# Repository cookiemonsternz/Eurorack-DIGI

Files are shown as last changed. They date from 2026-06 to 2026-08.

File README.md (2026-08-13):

# DIGI
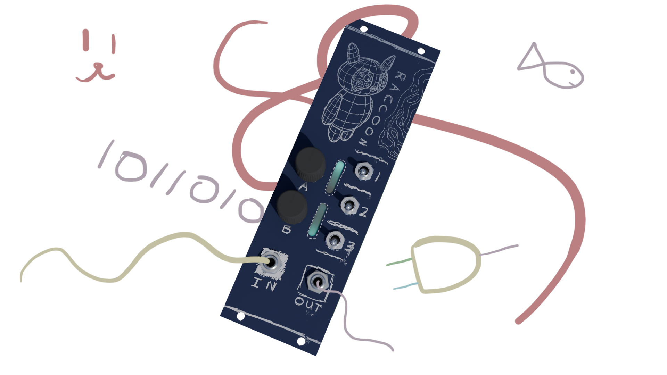
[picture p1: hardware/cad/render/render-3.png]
Render 3

_FPGA based programmable eurorack effects module_

#### What?
Yet another in my line of eurorack modules. This module is a prototyping platform for fpga based effects. It has a basic mono audio codec, two rotary encoders and 3 switches. It has two small led based displays in order to provide some feedback for the encoders. It consists of two user programmable leds with a diffuser.

DIGI utilises an ice40UP5K fpga chip, featuring 5280 luts and a 48Mhz clock. This is accompanied by a USB-SPI interface for easy programming. The board includes 64Mbits of PSRAM via single channel SPI and 256kbits of flash EEPROM. 

#### Why?
First and foremost: FPGAs are cool. Unfortunately, the world is quite starved of easy to use FPGA devboards, and especially so one which is designed for audio. This module acts as an easy to use prototyping environment for audio processing which would not be possible on MCUs.

This does kind of act as a counterpart to REV, but with an FPGA as to an MCU. This provides a bit more flexibility (and performance) and also provides a lot more memory to play with. 

#### How to use?
The board has a simple audio input and output, as well as two rotary encoders and switches, which are user programmable.

In terms of getting it set up, you'll need to program the fpga. To do this, follow the general setup guides for lattice radiant. It should be configured as a project for the iCE40UP5K-SG48I. An example showing the board acting as a basic buffer is available in the gateware folder.

Once assembled, the board uses a standard eurorack connector as well as standard 3.5mm audio jacks for input and output. Pretty plug and play :)

## Renders
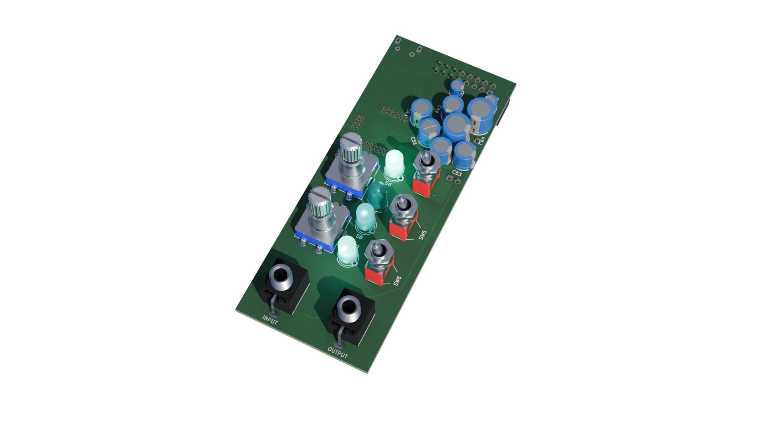
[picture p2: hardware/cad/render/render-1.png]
Render 1

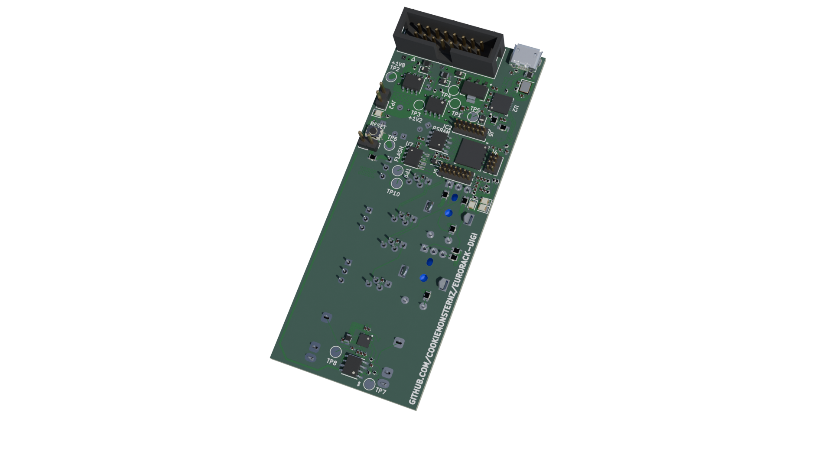
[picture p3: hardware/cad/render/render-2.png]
Render 2

Board front
Board back
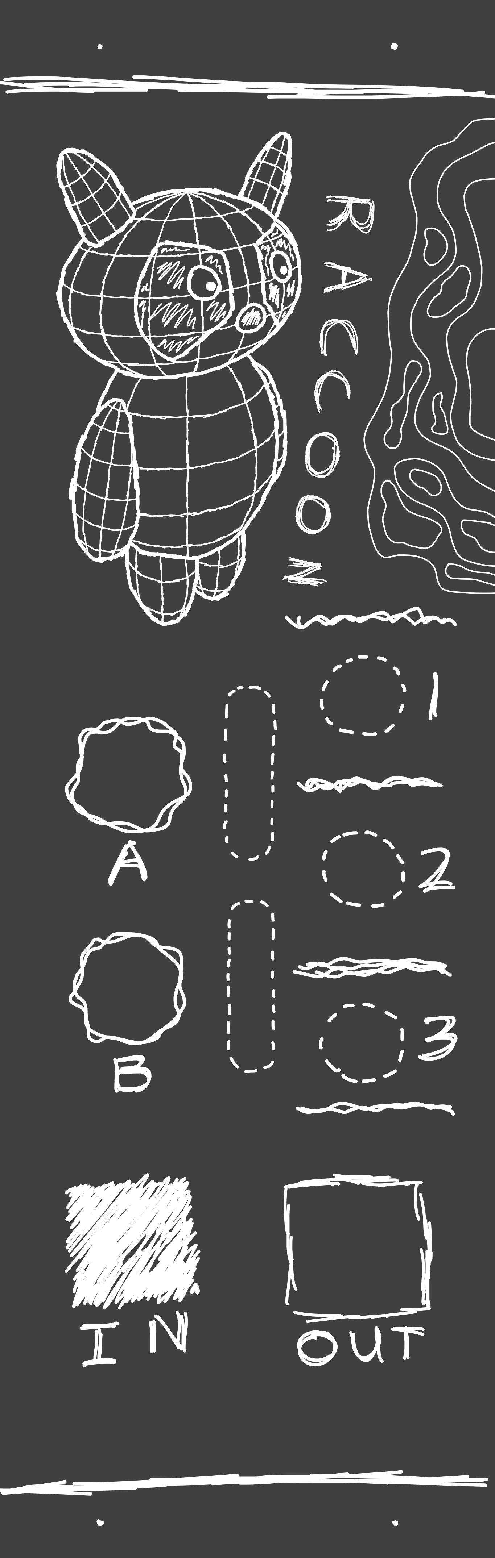
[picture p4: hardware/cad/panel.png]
Panel art


## Schematics
Schematics are available as a [pdf](./hardware/digi/plots/digi.pdf) or as svgs in [hardware/digi/plots](./hardware/digi/plots/).

## Zine Page
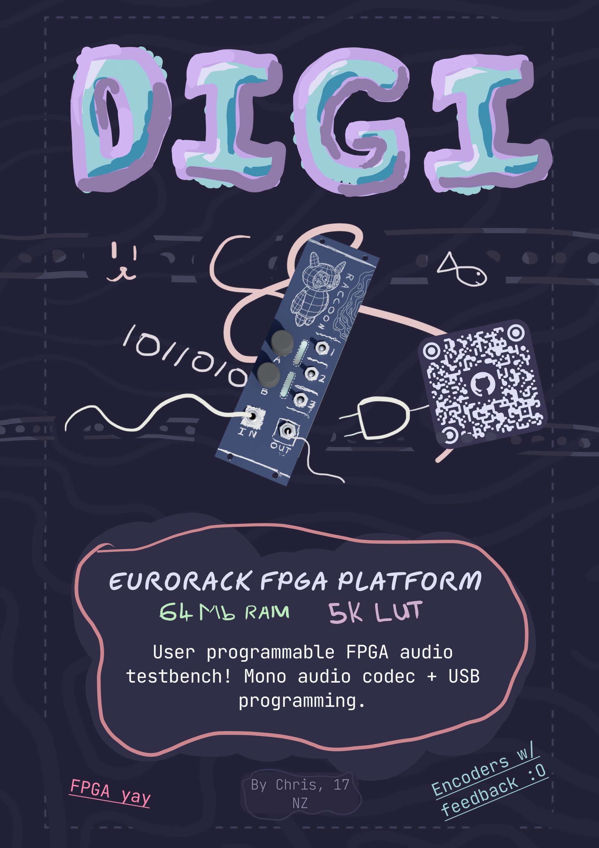
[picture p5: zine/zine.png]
Zine page


## BOM
_Needed is how many I personally need :)_
| Part | Quantity | Needed | Source | Link | Lot / Min Amount | Unit | Net | Running |
|---|---|---|---|---|---|---|---|---|
| **Capacitors** | | | | | | | | |
| 20p Cap, 0402 | 2 | 2 | JLCPCB | https://jlcpcb.com/partdetail/1906-0402CG200J500NT/C1554 | 1 | $0.0021 | $0.0042 | $0.01 |
| 10n Cap, 0402 | 4 | 4 | JLCPCB | https://jlcpcb.com/partdetail/15869-CL05B103KB5NNNC/C15195 | 1 | $0.0025 | $0.0100 | $0.01 |
| 100n Cap, 0402 | 25 | 25 | JLCPCB | https://jlcpcb.com/partdetail/291005-CL05B104KB54PNC/C307331 | 1 | $0.0076 | $0.1900 | $0.20 |
| 1u Cap, 0402 | 12 | 12 | JLCPCB | https://jlcpcb.com/partdetail/53938-CL05A105KA5NQNC/C52923 | 1 | $0.0069 | $0.0828 | $0.28 |
| 4.7u Cap, 0402 | 6 | 6 | JLCPCB | https://jlcpcb.com/partdetail/24469-CL05A475MP5NRNC/C23733 | 1 | $0.0107 | $0.0642 | $0.35 |
| 10u Cap, 0402 | 2 | 2 | JLCPCB | https://jlcpcb.com/partdetail/16204-CL05A106MQ5NUNC/C15525 | 1 | $0.0186 | $0.0372 | $0.38 |
| 22u Cap, 0603 | 1 | 1 | JLCPCB | https://jlcpcb.com/partdetail/60514-CL10A226MQ8NRNC/C59461 | 1 | $0.0224 | $0.0224 | $0.41 |
| 10u Electrolytic Cap, P1.5xD4.0 | 2 | 0 | LCSC | https://www.lcsc.com/product-detail/C503219.html | 10 | $0.0143 | $0.0000 | $0.41 |
| 47u Electrolytic Cap, P2.5xD6.3 | 5 | 0 | LCSC | https://www.lcsc.com/product-detail/C107641.html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 | 10 | $0.0665 | $0.0000 | $0.41 |
| 470u Electrolytic Cap, P5xD10.0 | 2 | 0 | LCSC | https://www.lcsc.com/product-detail/C338196.html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 | 5 | $0.1883 | $0.0000 | $0.41 |
| **Resistors** | | | | | | | | |
| 0? Resistor, 0402 | 6 | 6 | JLCPCB | https://jlcpcb.com/partdetail/17853-0402WGF0000TCE/C17168 | 1 | $0.001  | $0.0066 | $0.41 |
| 10? Resistor, 0402 | 1 | 1 | JLCPCB | https://jlcpcb.com/partdetail/25820-0402WGF100JTCE/C25077 | 1 | $0.001  | $0.0009 | $0.41 |
| 100? Resistor, 0402 | 4 | 4 | JLCPCB | https://jlcpcb.com/partdetail/25819-0402WGF1000TCE/C25076 | 1 | $0.0012 | $0.0048 | $0.42 |
| 470? Resistor, 0402 | 1 | 1 | JLCPCB | https://jlcpcb.com/partdetail/25860-0402WGF4700TCE/C25117 | 1 | $0.0010 | $0.0010 | $0.42 |
| 1k? Resistor, 0402 | 2 | 2 | JLCPCB | https://jlcpcb.com/partdetail/12256-0402WGF1001TCE/C11702 | 1 | $0.0011 | $0.0022 | $0.42 |
| 2.2k? Resistor, 0402 | 2 | 2 | JLCPCB | https://jlcpcb.com/partdetail/26622-0402WGF2201TCE/C25879 | 1 | $0.0010 | $0.0020 | $0.42 |
| 10k? Resistor, 0805 | 8 | 8 | JLCPCB | https://jlcpcb.com/partdetail/18102-0805W8F1002T5E/C17414 | 1 | $0.0034 | $0.0272 | $0.45 |
| 12k? Resistor, 0402 | 1 | 1 | JLCPCB | https://jlcpcb.com/partdetail/26495-0402WGF1202TCE/C25752 | 1 | $0.0010 | $0.0010 | $0.45 |
| 39k? Resistor, 0402 | 1 | 1 | JLCPCB | https://jlcpcb.com/partdetail/26526-0402WGF3902TCE/C25783 | 1 | $0.0011 | $0.0011 | $0.45 |
| 100k? Resistor, 0402 | 1 | 1 | JLCPCB | https://jlcpcb.com/partdetail/26484-0402WGF1003TCE/C25741 | 1 | $0.0010 | $0.0010 | $0.45 |
| 1M? Resistor, 0402 | 1 | 1 | JLCPCB | https://jlcpcb.com/partdetail/26826-0402WGF1004TCE/C26083 | 1 | $0.0011 | $0.0011 | $0.46 |
| **Diodes** | | | | | | | | |
| 1N4148WS, SOD-323 | 1 | 1 | JLCPCB | https://jlcpcb.com/partdetail/2485-1N4148WS/C2128 | 1 | $0.0092 | $0.0092 | $0.46 |
| 1N5819WS, SOD-323 | 4 | 4 | JLCPCB | https://jlcpcb.com/partdetail/GuangdongHottech-1N5819WS/C191023 | 1 | $0.0111 | $0.0444 | $0.51 |
| **Other Components** | | | | | | | | |
| TL072CDT | 1 | 1 | JLCPCB | https://jlcpcb.com/partdetail/STMicroelectronics-TL072CDT/C6961 | 1 | $0.1570 | $0.1570 | $0.67 |
| EC11 Rotary Encoder SW | 2 | 0 | Aliexpress | https://www.aliexpress.com/item/1005010400760178.html | 5 | $0.8580 | $0.0000 | $0.67 |
| SPDT Switch | 3 | 3 | Aliexpress | https://www.aliexpress.com/item/1005005370002265.html | 5 | $0.8520 | $4.2600 | $4.93 |
| PJ301M-12 Audio Jack | 2 | 0 | Aliexpress | https://www.aliexpress.com/item/1005004864182675.html | 10 | $0.4440 | $0.0000 | $4.93 |
| 2x08 IDC Connector | 1 | 0 | LCSC | https://www.lcsc.com/product-detail/C7430313.html | 5 | $0.0993 | $0.0000 | $4.93 |
| X322512MSB4SI 12MHz Crystal | 1 | 1 | JLCPCB | https://jlcpcb.com/partdetail/YXC_CrystalOscillators-X322512MSB4SI/C9002 | 1 | $0.0740 | $0.0740 | $5.00 |
| USB B Micro Port | 1 | 1 | JLCPCB | https://jlcpcb.com/partdetail/SHOUHAN-MicroXNJ/C404969 | 1 | $0.0406 | $0.0406 | $5.04 |
| 256kB EEPROM, AT24C256C-SSHL-T  | 1 | 1 | JLCPCB | https://jlcpcb.com/partdetail/MicrochipTech-AT24C256C_SSHLT/C6482 | 1 | $0.3886 | $0.3886 | $5.43 |
| 64Mbit PSRAM, APS6404L-SQN-SN | 1 | 1 | JLCPCB | https://jlcpcb.com/partdetail/APMemory-APS6404L_SQNSN/C5360304 | 1 | $2.4684 | $2.4684 | $7.90 |
| Neopixel tht, 5mm | 8 | 8 | Aliexpress | https://www.aliexpress.com/item/1005006447915276.html | 20 | $0.2595 | $5.1900 | $13.09  |
| Audio Codec, ES8311 | 1 | 1 | JLCPCB | https://jlcpcb.com/partdetail/1044199-ES8311/C962342 | 1 | $0.5514 | $0.5514 | $13.64  |
| Reset Button | 1 | 1 | JLCPCB | https://jlcpcb.com/partdetail/XUNPU-TS_1088AR02016/C720477 | 1 | $0.0551 | $0.0551 | $13.69  |
| Ferrite Bead, 600R | 2 | 2 | JLCPCB | https://jlcpcb.com/partdetail/Sunlord-GZ2012D601TF/C1017 | 1 | $0.0323 | $0.0646 | $13.76  |
| 22uH Inductor, 0805 | 2 | 2 | JLCPCB | https://jlcpcb.com/partdetail/Sunlord-SDFL2012T220KTF/C32375 | 1 | $0.0689 | $0.1378 | $13.90  |
| LED Yellow | 1 | 1 | JLCPCB | https://jlcpcb.com/partdetail/Hubei_KENTOElec-KT0805Y/C2296 | 1 | $0.0152 | $0.0152 | $13.91  |
| LED Green | 1 | 1 | JLCPCB | https://jlcpcb.com/partdetail/Hubei_KENTOElec-KT0805G/C2297 | 1 | $0.0162 | $0.0162 | $13.93  |
| LED Red | 1 | 1 | JLCPCB | https://jlcpcb.com/partdetail/85425-NCD0805R1/C84256 | 1 | $0.0133 | $0.0133 | $13.94  |
| AMS1117-3.3 | 1 | 1 | JLCPCB | https://jlcpcb.com/partdetail/Advanced_MonolithicSystems-AMS1117_33/C6186 | 1 | $0.1971 | $0.1971 | $14.14  |
| XL1509-ADJ | 2 | 2 | JLCPCB | https://jlcpcb.com/partdetail/XLSEMI-XL1509ADJE1/C74192 | 1 | $0.2717 | $0.5434 | $14.68  |
| **Other** | | | | | | | | |
| PCB | 1 | 1 | JLCPCB | NA | 5 | $1.6600 | $8.3000 | $22.98  |
| Aluminium Plate (100x200x2mm) | 1 | 1 | Aliexpress | https://www.aliexpress.com/item/1005007160296738.html | 1 | $6.2300 | $6.2300 | $29.21  |
| **Total** | | | | | | | | $29.21  |

| **Totals** | **Money**  |
|---|---|
| Aliexpress, Inc. Shipping + Tax | $24.57 |
| JLCPCB, Inc. Shipping + Tax | $38.84 |
| Total | $63.41 |

## CAD Links
Heres the links to the CAD source, Onshape:
[Panel source](https://cad.onshape.com/documents/423b155ae421053f9c0db9a4/w/13826012c5a1515169c92444/e/776c4f51f2d171959c208a60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)

## Directory Structure
- **hardware/**
    - **bom/** - BOM Files (CSV and LibreOffice Calc)
    - **cad/** - CAD Files
        - **render/** - Files for rendering (inc. gltf models)
    - **digi/** - KiCad files
        - **lib/** - External libraries
        - **production/** - Production files (Gerber, etc.)
        - **plots/** - Schematic plot
- **journals/**
- **zine/** - Zine page

#### This project was created for [Hack Club](https://hackclub.com/) - [Fallout](https://fallout.hackclub.com/)

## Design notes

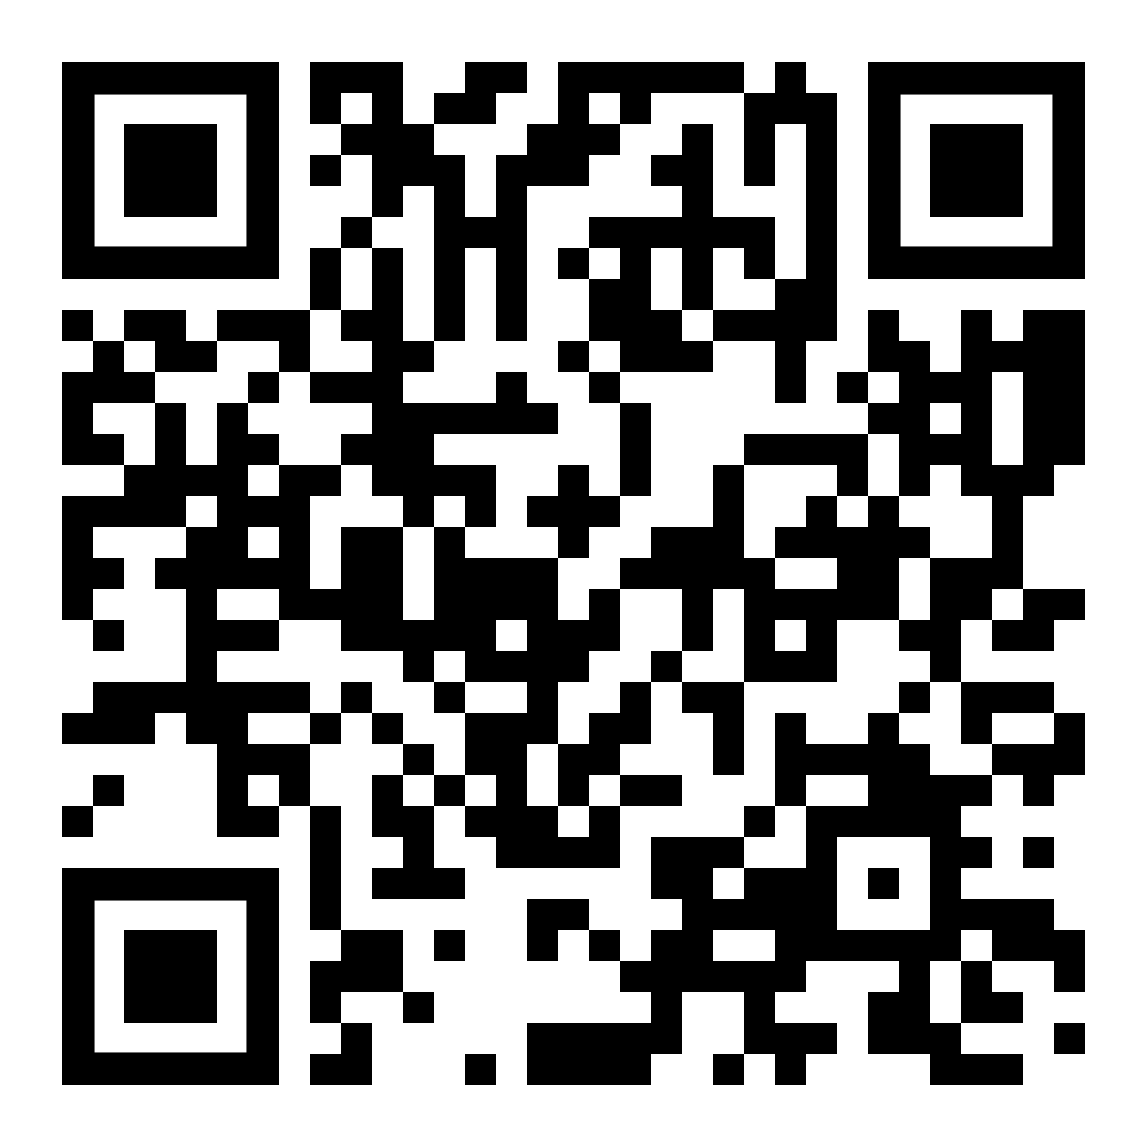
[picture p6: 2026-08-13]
hardware/digi/github-qr.png

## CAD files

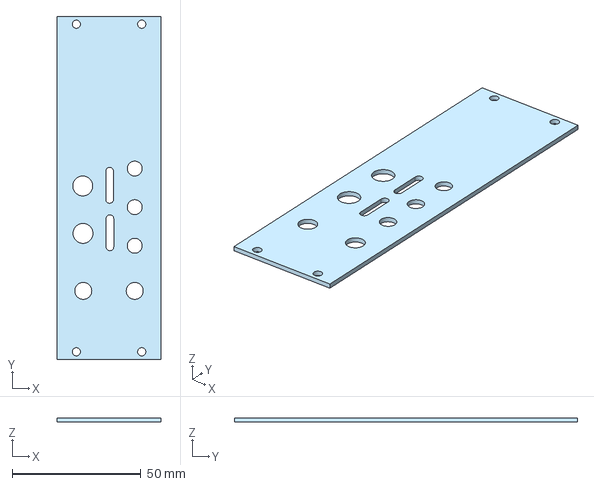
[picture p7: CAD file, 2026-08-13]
hardware/cad/panel.step
40.2 x 133.3 x 1.59 mm

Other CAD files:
hardware/cad/panel.dxf

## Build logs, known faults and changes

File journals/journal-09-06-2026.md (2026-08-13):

# DIGI Journal 2 - 09/06/2026

Hello again!
Today I've already done some work tidying up loose ends with the audio codec and usb-spi interface, and I'm happy to say that they are both much closer to complete. It takes ages to do anything really with them, sooo much datasheet reading lol.

Anyways, I'm about to move on to the power section for the board, and have quickly mocked it up in figma:
Power layout

And going into kicad:
Kicad power section
Just went with LDOs / buck-buck conv. which were basic parts. 1.2V is the very lower end for the chip but it should be fine

---

A couple days later and I've just been doing a bunch of random odd bits around the place. 
I've added a couple inputs (2 rotary encoders and 3 switches), as well as 8 neopixels for encoder feedback (4 per encoder).
Encoder feedback leds

I also got the crystal sorted out, just using basic parts etc.
Overall, I reckon the schematic is very very close to being done :) I'm going to do a final pass over everything, and maybe add another feature or two, as I've still got 13 unused GPIO pins.

In terms of audio as I mentioned earlier, I'm going to go with the approach of discarding half the differential pair. It'll still work and be mostly fine, and it saves me from making a balanced to unbalanced converter, which turns out to be suprisingly complex.

---

I've decided to add a little flash chip as well, just for persistent configuration. Just using a cheap wee one from the basic parts. Uses i2c so I can just redo the i2c bus I've already got set up.
Flash

I've also just figured that I might need a level shifter for the sdram :( It runs at 1.8V and the fpga runs at 3.3V.

Yep my suspicions were correct, it can only tolerate ~2.4V. There is an easier solution however: Because each bank of the ice40 chip has a seperate vcc, I can just power the spi block at 1.8V.

A problem with this is that the USB interface ic runs at 3.3v, so I've decided to just use two spi sets. The ice40 has two hardware spi interfaces, so I've put one of them on bank 1 at 1.8V for the sdram, and the other on bank 2 at 3.3V for the USB-SPI interface. Pretty chill :)

And after doing a final pass and adding a bunch of test points, I'm happy to call the schematic complete! 

---

Next up, footprint assignment / BOM, god I'm not looking forward to this lol.

---

Welp it took about as long as I thought it would, but its done now :)
BOM
Annnd of course half my time didn't get tracked because the resume button broke :( Oh well, time to get onto the pcb.

And heres how its looking:
PCB Pre-layout

I'm going to aim for a pretty dense layout, as there won't be much on the top of the board and I don't want it to look tooo sparse. I might go for an 8hp module this time, which would mean 40.64mm wide panel and thus probs a ~40x100mm board.

And yeah, this is looking pretty doable:
PCB Pre-layout w/ Board outline

This is what I'm thinking for the general layout:
General layout

---

Ended the day here, continued in next journal :)

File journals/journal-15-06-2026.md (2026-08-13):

# DIGI Journal 3 - 15/06/2026

Welp its been a minute! Getting straight back into the swing of things though. Goal for today is a finished pcb and panel, maybe even some panel art and if I'm really lucky, a readme :)

First things first though, I'd like to make this board just a tiny bit more general purpose by exposing some headers :) Just some of the pins on each bank.
Headers
Pretty simple stuff, not too much of note to talk about, just hope it isn't too annoying to route lol.

---

I've layed out the first two ldo's, the 3.3V and 1.8V, looks like this:
LDO 1 and 2 layout

And all three:
Die ganze dinge

The audio codec:
Audio codec layout

Going through the ftdi chip now and I've decided to swap out the electrolytic caps with mlcc ones, just to save some space. Heres the layed out section:
FTDI Layout

I've also decided to cut the number of neopixels in half, they're just really big lol.
They'll be layed out like so:
Neopixel layout
I'll have a little slot with some diffusion paper and a barrier between the two encoders and that should give a decent vertical slider like representation.

The routing here is super basic:
Neopixels layout pcb

Now the hard part: I've started routing the actual fpga chip, and have made it to about here:
FPGA Routing pt 1
Theres still a few more components to go in (just the reset and done led), which shouldn't be terrible, but man these headers are complicating things :sob: I'm going to leave it for a minute and route another section, but it does need to get done eventually.

Welp, I sorted out the flash which was quite easy, as well as all the pullups for the encoders but now theres nothing left to do but route stuff around the fpga :O

ARrrgghh 

Tomorrow job :)

Heres where I ended off for today:
PCB at end of day

Gn :)

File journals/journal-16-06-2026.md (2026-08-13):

# DIGI Journal 4 - 16/06/2026

Hello again! Its tomorrow now :)
I've already done a bunch of work before starting this journal, but generally, its just been a bunch of routing. Heres the result of that so far:
Routing
Everything is routed except for the power! Yippee!

For the power, I do need to take a bit of care. I've got a dedicated layer just to do a bunch of big pours which should be pretty chill.

---

And a wee bit later heres the fully routed layout!
Fully routed

And after a bit more work, no more drc errors :)
DRC Errors

Well there are a few, but none of them are actual errors. Theres also a crapton of silkscreen warnings because I haven't gone through and sorted it out yet.

Heres the front silkscreen:
Front silkscreen

And the back:
Back silkscreen

I do want to add a bit of art to both sides, but that can wait for later. I was going to use a QR code for the thing but I didn't have space and there were far too many holes, text is just easier :)

And that (mostly) concludes the board design section of this project! Yayyy! Next up is the panel and such, but that will have to wait for tomorrow unfortunately.

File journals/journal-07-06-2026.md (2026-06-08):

# DIGI Journal 1 - 07/06/2026

Hello again! The 4 am brain demands another project, and in the depths of my deranged, sleep deprived mind I have come up with an absolutely horrifying idea for the next model in my line of effects. 

A digital effect pedal based on an fpga chip.

I've been looking for an excuse to screw around with fpga for ages, and dsp is one application they're really well suited for. My aim is for this to be a general purpopse-ish design, so I can program a bunch of different effects in the future. 

I've already done a bit of research on parts, and decided what I'm going to use, so I'll just give a quick overview here:

### The FPGA Chip

I've elected to go with the ice40UP5k. There were a couple main factors that went into this decision:
- Its available on jlcpcb pcba
- Its cheap-ish ($8.00, most are more)
- Has a good amount of luts (5k :))
- Is very popular (and thus well supported)

It generally looks like a pretty simple and usable chip, which is very appealling to me.

### Ram

Because I want this to be reasonably general purpose, I'm going to need more than the MBit sram included in the ice40up5k. At a sample rate of 44.1khz and bit depth of 12, that would give me only ~1.5 seconds of audio storage, and I would like a wee bit more for longer reverbs / delays. I've decided to go with the 
APS6404L-SQN-SN chip, which is a 64MBit PSRAM (pretty much sram but a different technology, only used it because it was cheap and for the features I'm about to mention). 
I chose this chip because:
- Storage capacity is good (like 2 mins of audio)
- Cheap (cheaper than sram, thats for sure, still about 3 bucks but thats fine)
- QSPI interface - A lot of sram uses parallel interfaces, but those would eat up way too many pins on the fpga (one i was looking at earlier used 37, the fpga has 48 :O)

### Audio Codec

Unfortunately I can't pull the same trick I did with the rp2040 for audio, and just pwm out, adc in, as the ice40up doesn't have an adc. To that end, I'll need an audio codec, which provides an audio input and output via i2c. I've just gone with the most stocked option on jlcpcb, which was the  . Its a mono audio codec, 24 bit at up to 96kHz which is well beyond what I need. I'm pretty sure its reasonably common, there was a lot of results for it when I searched it up and the documentation seems alright.

So yeah, thats the beginning of the hardware decisions for this module. Next up is really just getting started on the schematic tbh. Luckily for me, theres an open source ice40up breakout board, which will be super handy for everything really.

annnd of course the reference design uses some wacky old software I need to download >:(

---

Its now the next day and I've realised I'm a bit of an idiot, there is actually the schematic available just in the datasheet for the example board :( I'm going to go through it now and start working on some of my schematic.

Getting straight into the meat of it, heres the first bit I've done. Its just all the filtering for the fpga chip:
FPGA Chip Filtering

And then the reset button and status led:
Reset button + LED

Looking into usb connection now, and it'll require a usb to spi chip, or maybe to i2c but the demo uses spi and I'm inclined to do so also. I spent like half an hour trying to read and setup some other, only to realise it was the complete wrong type of chip :O. I eventually settled on the FT4222HQ USB-SPI Interface. The circuits kinda half done but I'm not yet sure what to do with the rest of it, so I'm leaving it for now and I'll come back later:
USB-SPI

Just realised my audio codec sends audio over i2s, not i2c, two different things lol. I2S is the standard for audio, but no dedicated hardware support on the fpga, so I'll have to write my own, which shouldn't be too bad.

Heres the finished circuit for the audio codec:
Audio codec circuit
The output isn't ideal yet, will only have half the power of the full thing since i'm discarding half of the differential pair. I might look into summing them later.

Next up the ram, this ones pretty easy:
RAM
Not using the QSPI interface, just regular :)

And some inputs:
Inputs

All thats left now is the power supply stuff (I think), but that requires brain work and my brain is dead. I'm gonna call it here for today :)

gn

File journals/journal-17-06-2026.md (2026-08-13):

# DIGI Journal 5 - 17/06/2026 and 22/07/2026

Hello again! Today is a new day and this day, it is a day for cad!
First things first, I sketched out the design of the panel in onshape:
Sketch

And in 3d:
3D

---

Lowkey fallout has already been now! getting back into the swing of things just now :)

Looking back over what I've done, and it seems that all thats left to do is the admin stuff. The main project is about ready to go! Heres a list:
- [ ] Renders
- [ ] Zine
- [ ] Firmware
- [ ] Readme
- [ ] Check submission requirements

I think i'm going to start with firmware, as it looks to be the most straightforward atm given my lack of a drawing tablet (i'm at school).

---

After a bit of setup, I now have a basic blinky example going! No testing yet obviously but it seems like it'll feasibly work.

Next up writing an actual audio demo program :)

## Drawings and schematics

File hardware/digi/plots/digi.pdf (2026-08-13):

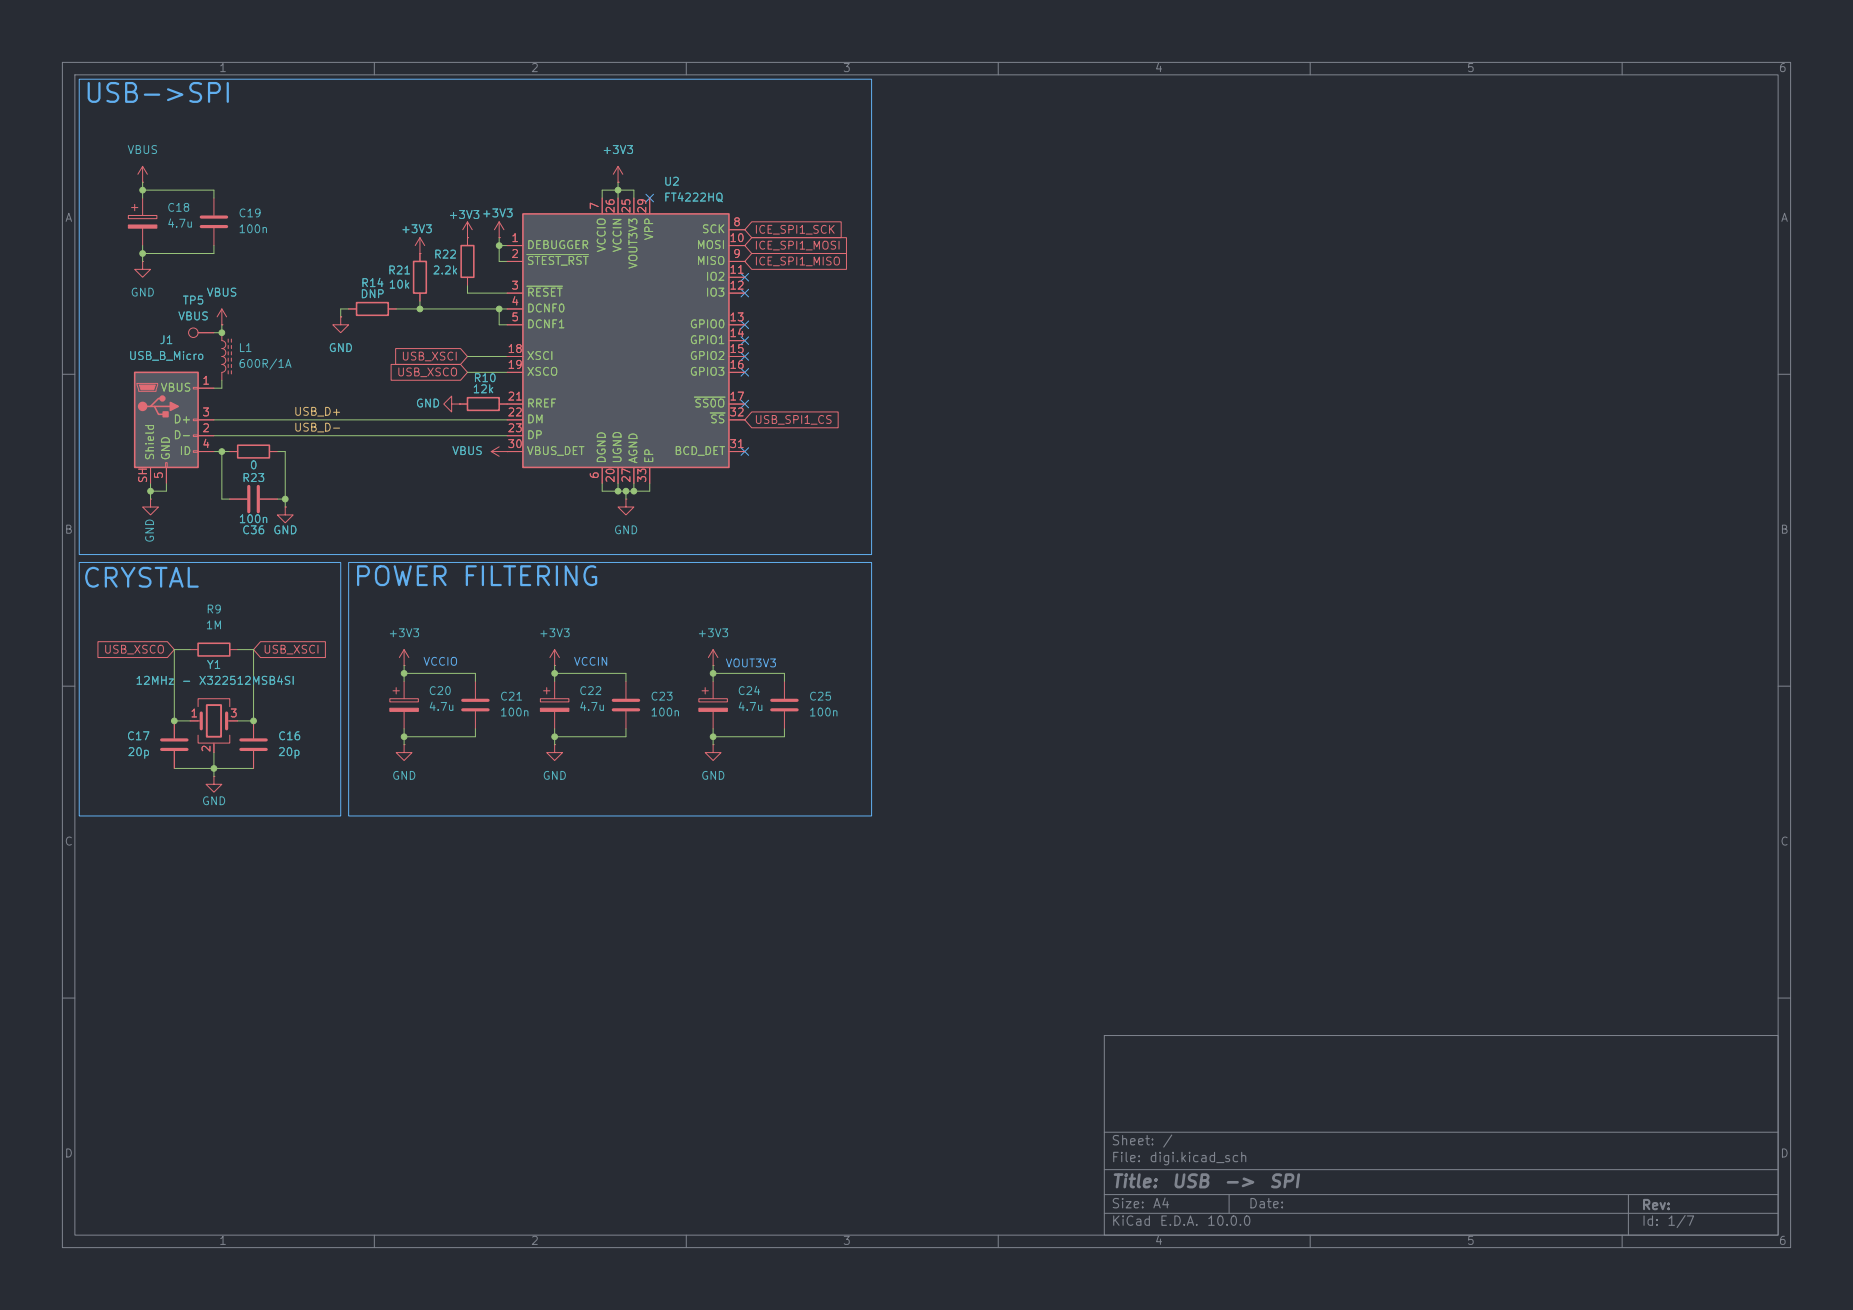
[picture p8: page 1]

Size: A4 | Rev:
KiCad E.D.A. 10.0.0 | Id: 1/7

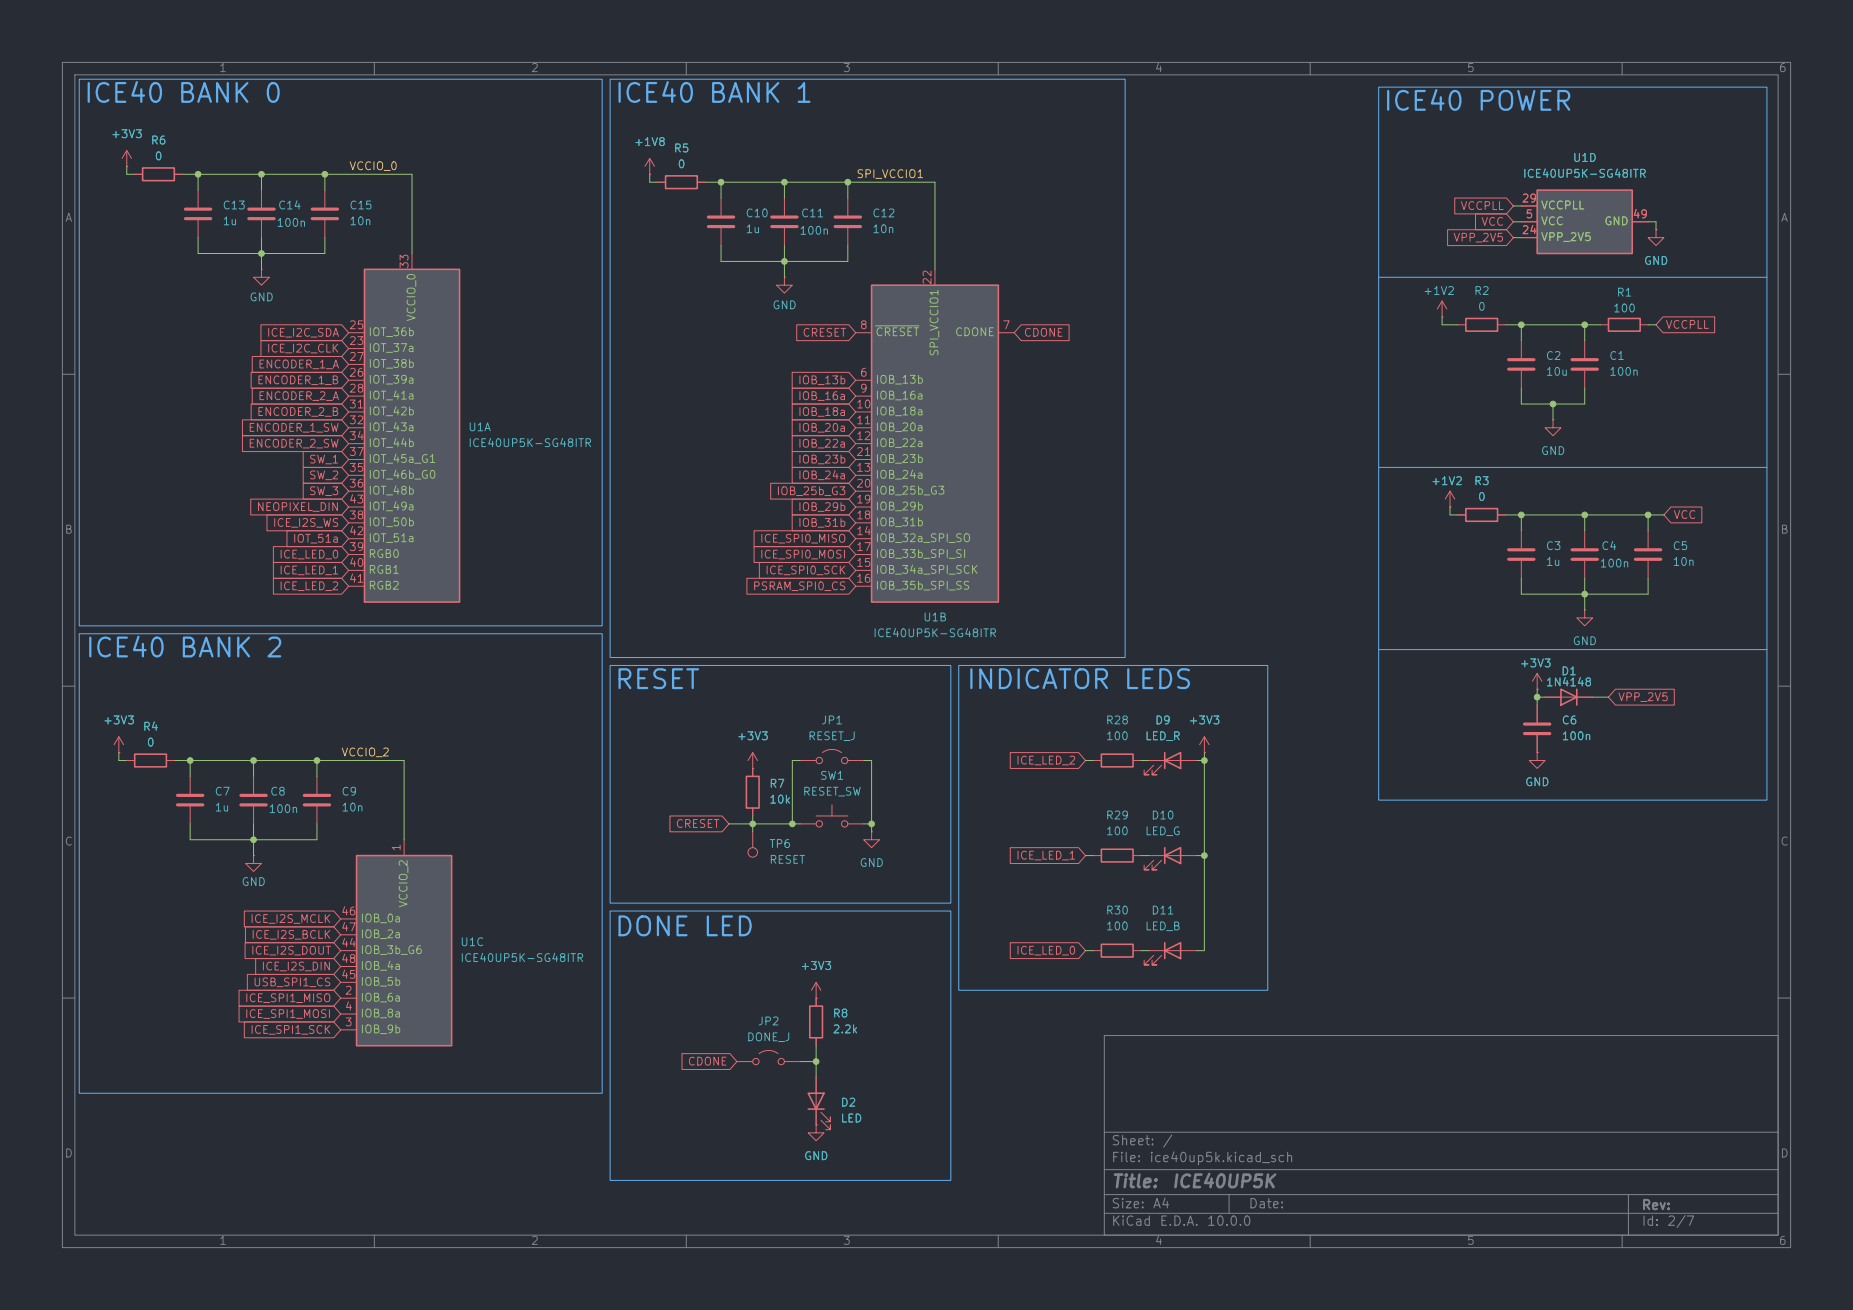
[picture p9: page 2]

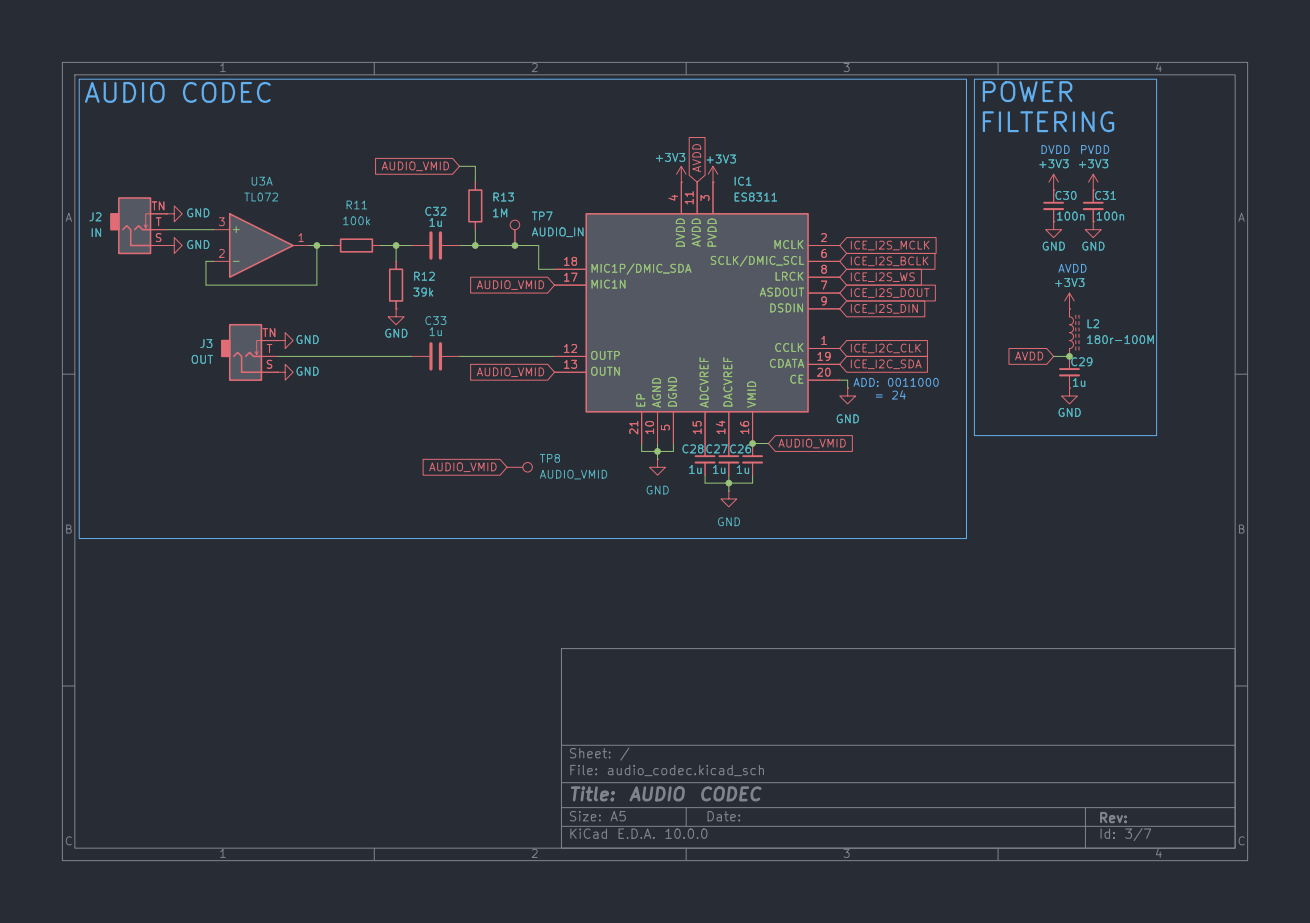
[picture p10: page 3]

Size: A5 | Rev: | C Date:
KiCad E.D.A. 10.0.0 | Id: 3/7

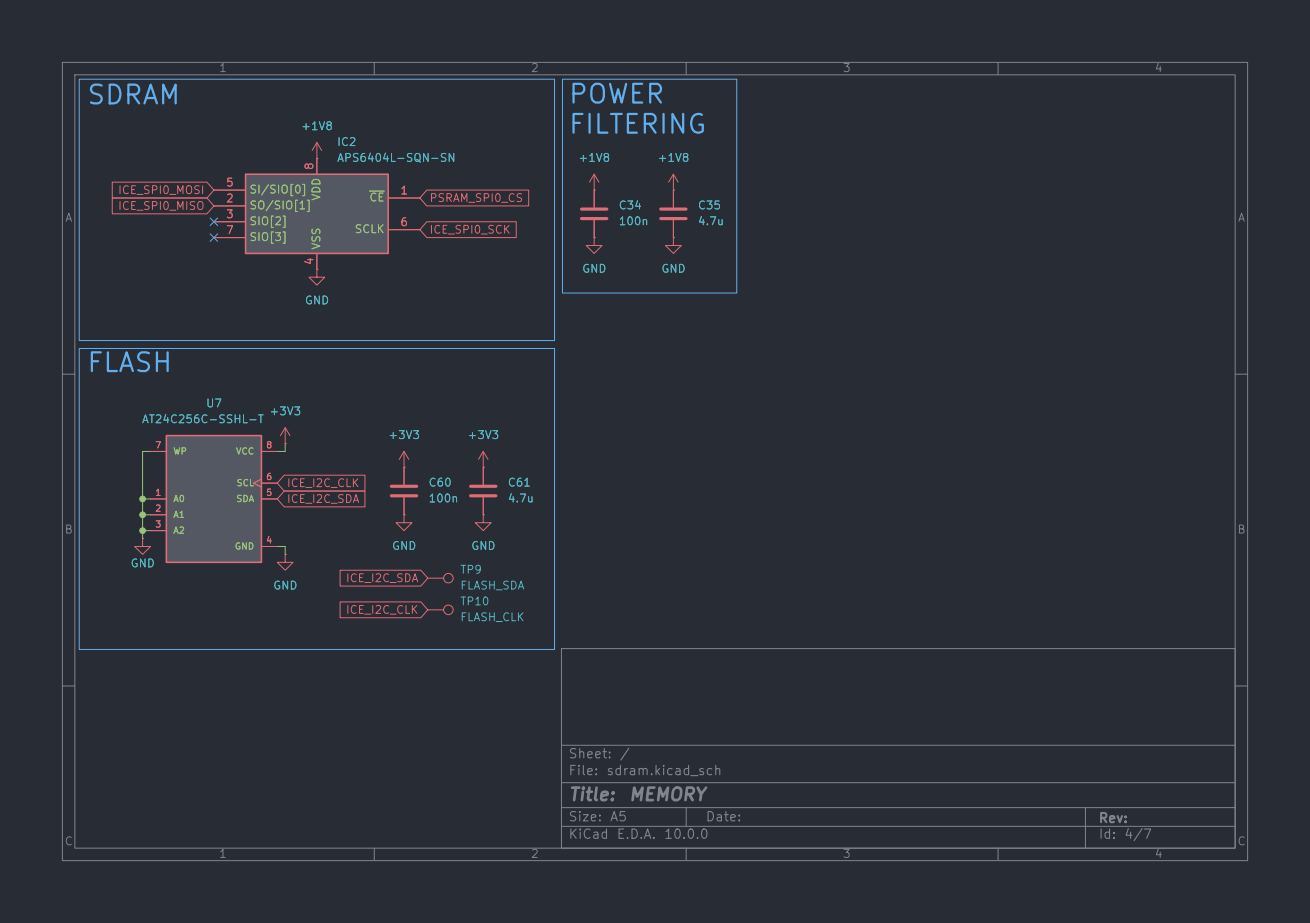
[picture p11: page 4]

Size: A5 | Rev: | C Date:
KiCad E.D.A. 10.0.0 | Id: 4/7

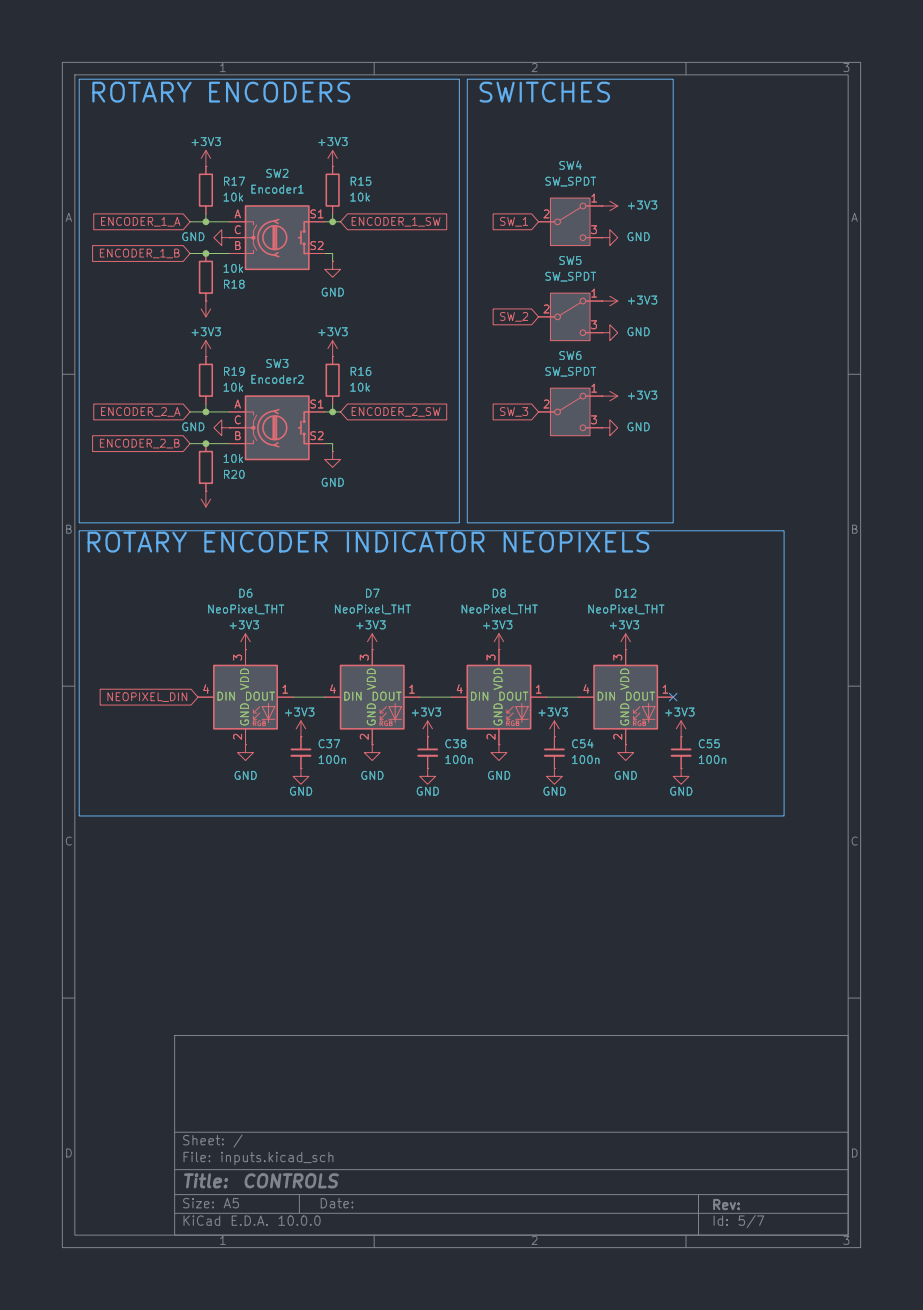
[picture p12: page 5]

ROTARY ENCODER INDICATOR NEOPIXELS

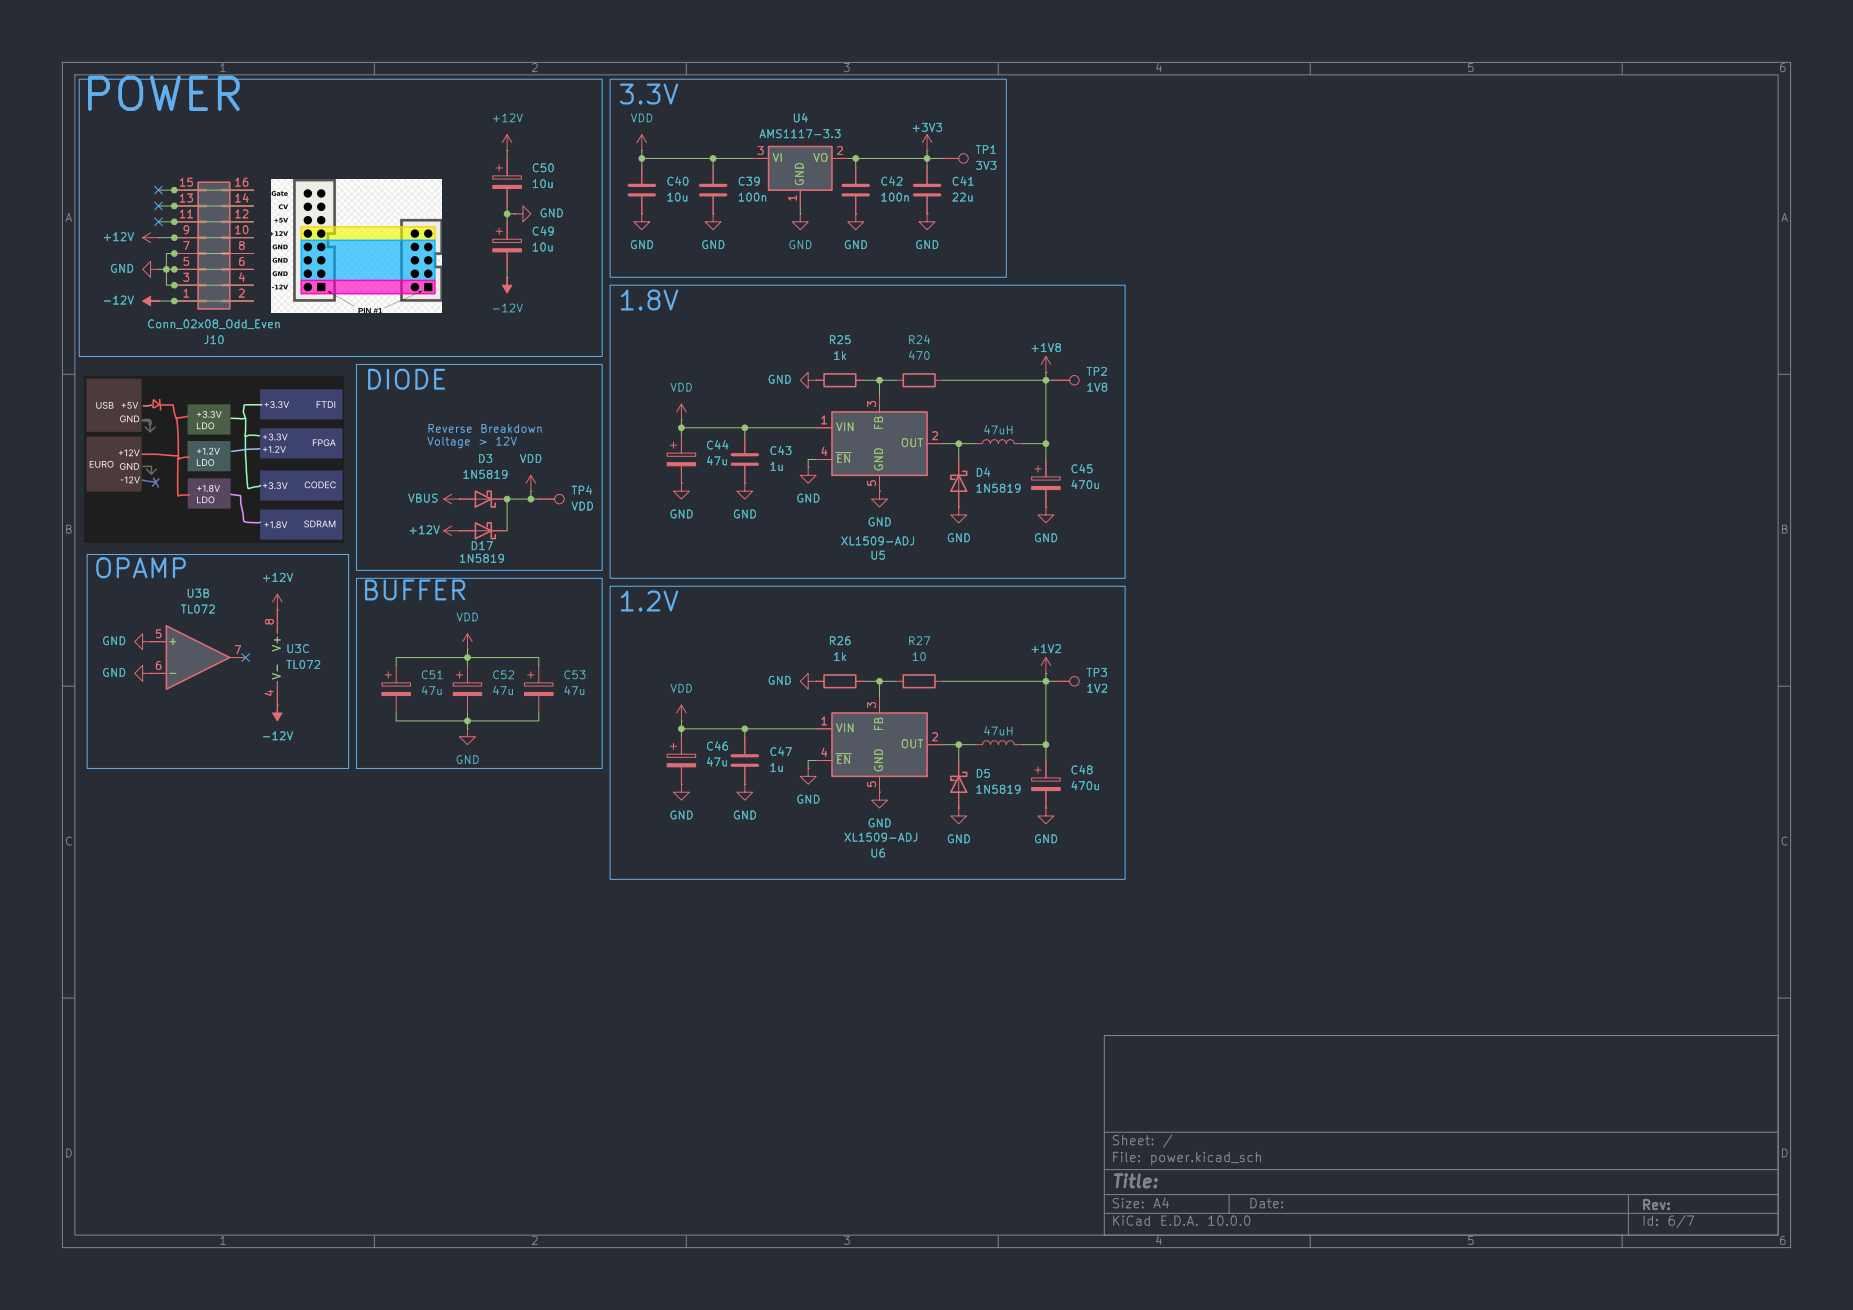
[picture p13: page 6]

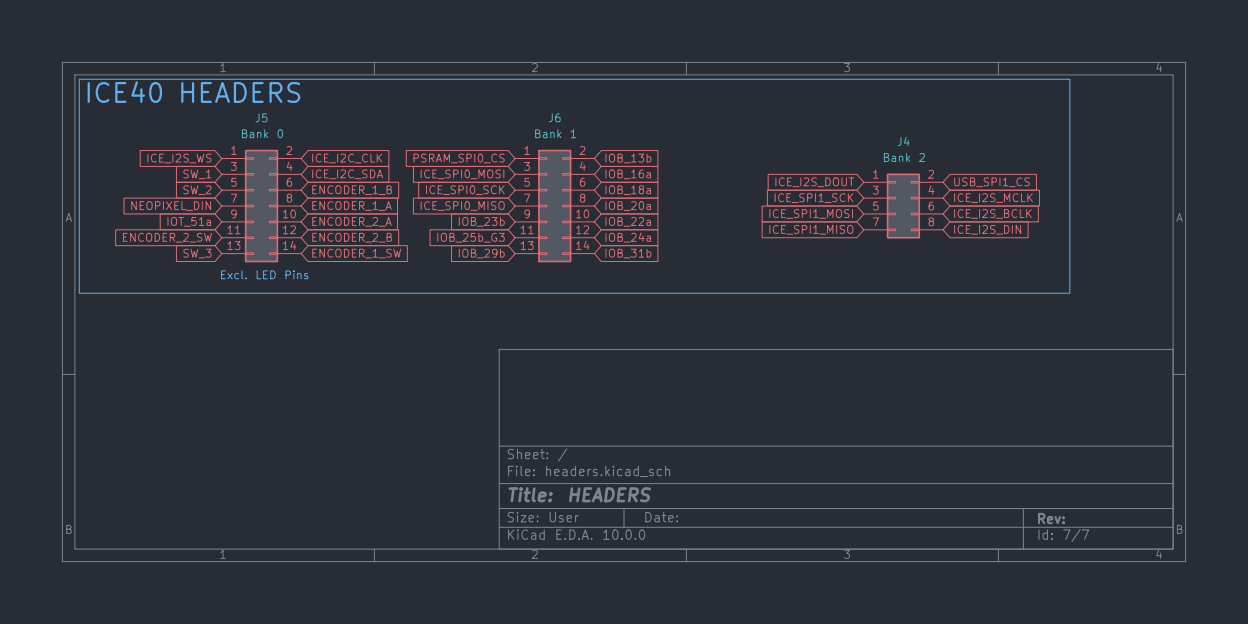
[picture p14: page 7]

Excl. LED Pins ICE40 HEADERS

Size: User | Rev:
KiCad E.D.A. 10.0.0 | Id: 7/7

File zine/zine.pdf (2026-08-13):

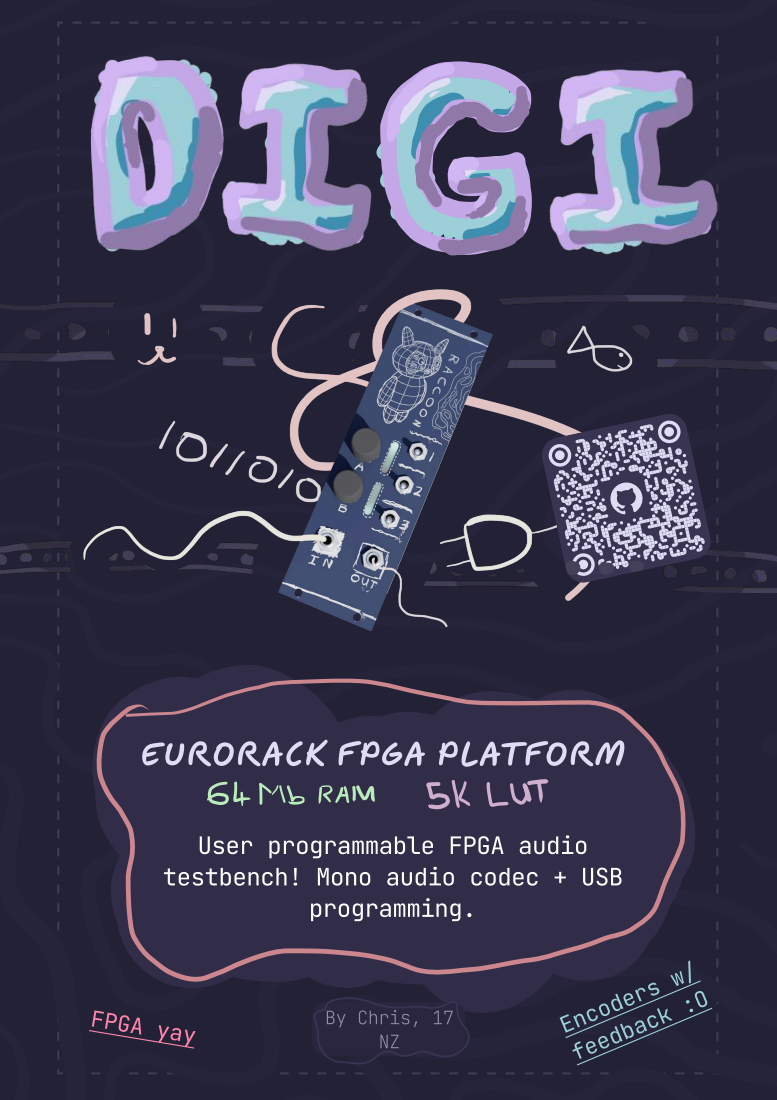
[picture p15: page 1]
FPGA yay; programming.; Encoders w/ feedback :O; By Chris, 17 NZ

EURORACK FPGA PLATFORM

User programmable FPGA audio
testbench! Mono audio codec + USB

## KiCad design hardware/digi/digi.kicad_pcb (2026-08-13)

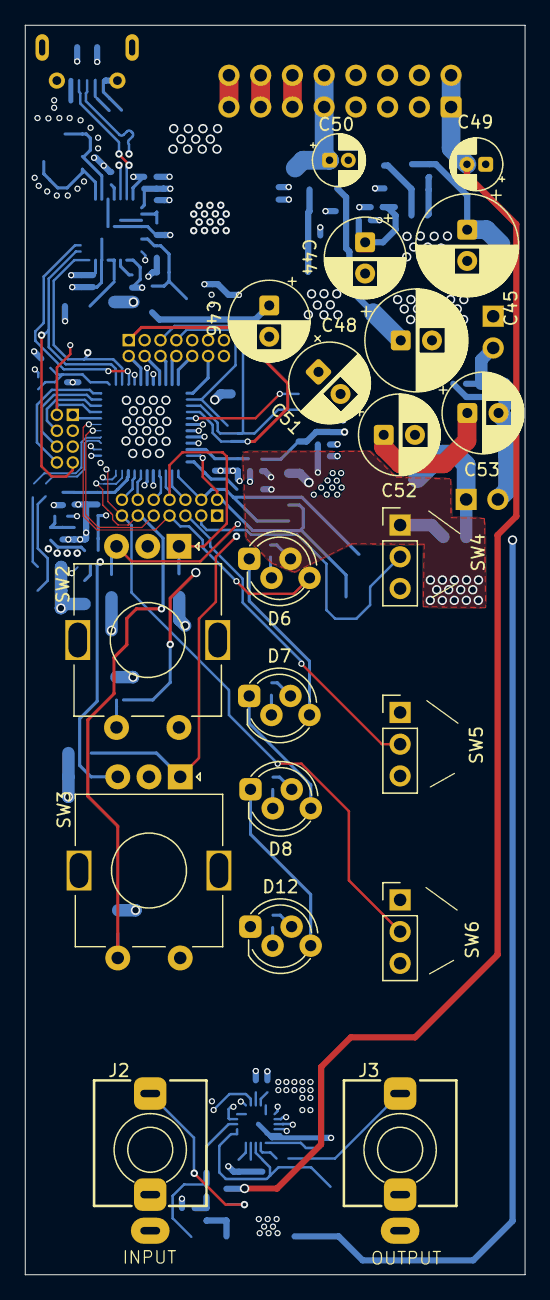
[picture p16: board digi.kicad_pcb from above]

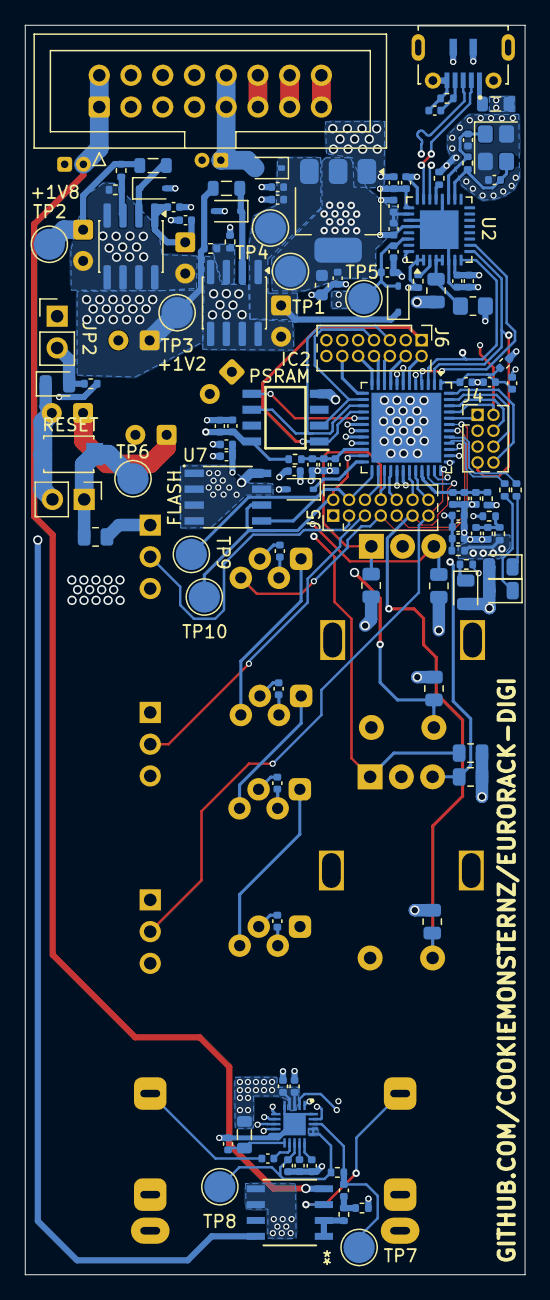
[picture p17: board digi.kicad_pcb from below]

Board: 6 copper layers, 40.0 x 100.0 mm, 139 parts (119 on the bottom side), 86 nets.

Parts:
C1, C4, C6, C8, C11, C14, C19, C21, C23, C25, C30, C31, C34, C36, C37, C38, C39, C42, C54, C55, C60: 100n; C_0402_1005Metric
C2, C40: 10u; C_0402_1005Metric
C3, C7, C10, C13, C26, C27, C28, C29, C32, C33, C43, C47: 1u; C_0402_1005Metric
C5, C9, C12, C15: 10n; C_0402_1005Metric
C16, C17: 20p; C_0402_1005Metric
C18, C20, C22, C24, C35, C61: 4.7u; C_0402_1005Metric
C41: 22u; C_0603_1608Metric
C44, C46, C51, C52, C53: 47u; CP_Radial_D6.3mm_P2.50mm
C45, C48: 470u; CP_Radial_D8.0mm_P2.50mm
C49, C50: 10u; CP_Radial_D4.0mm_P1.50mm
D1: 1N4148; D_SOD-323
D2: LED; LED_0805_2012Metric
D3, D4, D5, D17: 1N5819; D_SOD-323
D6, D7, D8, D12: NeoPixel_THT; LED_D5.0mm-4_RGB_Staggered_Pins
D9: LED_R; LED_0805_2012Metric
D10: LED_G; LED_0805_2012Metric
D11: LED_B; LED_0805_2012Metric
IC1: ES8311; QFN40P300X300X60-21N
IC2: APS6404L-SQN-SN; SOIC127P600X175-8N
J1: USB_B_Micro; SHOUHAN_MICROXNJ
J2: IN; Jack_3.5mm_QingPu_WQP-PJ301M-12_Vertical
J3: OUT; Jack_3.5mm_QingPu_WQP-PJ301M-12_Vertical
J4: Bank 2; PinHeader_2x04_P1.27mm_Vertical
J5: Bank 0; PinHeader_2x07_P1.27mm_Vertical
J6: Bank 1; PinHeader_2x07_P1.27mm_Vertical
J10: Conn_02x08_Odd_Even; IDC-Header_2x08_P2.54mm_Vertical
JP1: RESET_J; PinHeader_1x02_P2.54mm_Vertical
JP2: DONE_J; PinHeader_1x02_P2.54mm_Vertical
L1: 600R/1A; L_0805_2012Metric
L2: 180r-100M; L_0805_2012Metric
L3, L4: 47uH; L_0805_2012Metric
R1, R28, R29, R30: 100; R_0402_1005Metric
R2, R3, R4, R5, R6, R23: 0; R_0402_1005Metric
R7, R15, R16, R17, R18, R19, R20, R21: 10k; R_0805_2012Metric
R8, R22: 2.2k; R_0402_1005Metric
R9, R13: 1M; R_0402_1005Metric
R10: 12k; R_0402_1005Metric
R11: 100k; R_0402_1005Metric
R12: 39k; R_0402_1005Metric
R14: DNP; R_0805_2012Metric_Pad1.20x1.40mm_HandSolder
R24: 470; R_0402_1005Metric
R25, R26: 1k; R_0402_1005Metric
R27: 10; R_0402_1005Metric
SW1: RESET_SW; SW_TS-1088-AR02016
SW2: Encoder1; RotaryEncoder_Alps_EC11E-Switch_Vertical_H20mm_MountingHoles
SW3: Encoder2; RotaryEncoder_Alps_EC11E-Switch_Vertical_H20mm_MountingHoles
SW4, SW5, SW6: SW_SPDT; PinHeader_1x03_P2.54mm_Vertical
TP1: 3V3; TestPoint_Pad_D2.5mm
TP2: 1V8; TestPoint_Pad_D2.5mm
TP3: 1V2; TestPoint_Pad_D2.5mm
TP4: VDD; TestPoint_Pad_D2.5mm
TP5: VBUS; TestPoint_Pad_D2.5mm
TP6: RESET; TestPoint_Pad_D2.5mm
TP7: AUDIO_IN; TestPoint_Pad_D2.5mm
TP8: AUDIO_VMID; TestPoint_Pad_D2.5mm
TP9: FLASH_SDA; TestPoint_Pad_D2.5mm
TP10: FLASH_CLK; TestPoint_Pad_D2.5mm
U1: ICE40UP5K-SG48ITR; QFN-48-1EP_7x7mm_P0.5mm_EP5.6x5.6mm
U2: FT4222HQ; VQFN-32-1EP_5x5mm_P0.5mm_EP3.1x3.1mm
U3: TL072; D8_TEX_STM
U4: AMS1117-3.3; SOT-223-3_TabPin2
U5, U6: XL1509-ADJ; SOIC-8_3.9x4.9mm_P1.27mm
U7: AT24C256C-SSHL-T; SOIC127P600X175-8N
Y1: 12MHz - X322512MSB4SI; Crystal_SMD_3225-4Pin_3.2x2.5mm

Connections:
+1V2: C48.1, L4.2, R2.1, R3.1, R27.2, TP3.1 (1_1)
+1V8: C34.1, C35.1, C45.1, IC2.8 (VDD), L3.2, R5.1, R24.2, TP2.1 (1_1)
+3V3: C6.1, C20.1, C21.1, C22.1, C23.1, C24.1, C25.1, C30.1, C31.1, C37.1, C38.1, C41.1, C42.1, C54.1, C55.1, C60.1, C61.1, D1.2 (A), D6.3 (VDD), D7.3 (VDD), D8.3 (VDD), D9.2 (A), D10.2 (A), D11.2 (A), D12.3 (VDD), IC1.3 (PVDD), IC1.4 (DVDD), L2.1, R4.1, R6.1, R7.1, R8.1, R15.1, R16.1, R17.1, R18.1, R19.1, R20.1, R21.2, R22.2, SW4.1 (A), SW5.1 (A), SW6.1 (A), TP1.1 (1_1), U2.1 (DEBUGGER), U2.2 (~STEST_RST), U2.7 (VCCIO), U2.25 (VOUT3V3), U2.26 (VCCIN), U4.2 (VO), U7.8 (VCC)
+12V: C50.1, D17.2 (A), J10.9, J10.10, U3.8 (V+)
-12V: C49.2, J10.1, J10.2, U3.4 (V-)
/SPI_VCCIO1: C10.1, C11.1, C12.1, R5.2, U1.22 (SPI_VCCIO1)
/USB_D+: J1.3 (D+), U2.22 (DM)
/USB_D-: J1.2 (D-), U2.23 (DP)
/VCCIO_0: C13.1, C14.1, C15.1, R6.2, U1.33 (VCCIO_0)
/VCCIO_2: C7.1, C8.1, C9.1, R4.2, U1.1 (VCCIO_2)
AUDIO_VMID: C26.1, IC1.13 (OUTN), IC1.16 (VMID), IC1.17 (MIC1N), R13.2, TP8.1 (1_1)
AVDD: C29.1, IC1.11 (AVDD), L2.2
CDONE: JP2.1 (A), U1.7 (CDONE)
CRESET: JP1.1 (A), R7.2, SW1.1, TP6.1 (1_1), U1.8 (~CRESET)
ENCODER_1_A: J5.8, R17.2, SW2.A, U1.27 (IOT_38b)
ENCODER_1_B: J5.6, R18.2, SW2.B, U1.26 (IOT_39a)
ENCODER_1_SW: J5.14, R15.2, SW2.S1, U1.32 (IOT_43a)
ENCODER_2_A: J5.10, R19.2, SW3.A, U1.28 (IOT_41a)
ENCODER_2_B: J5.12, R20.2, SW3.B, U1.31 (IOT_42b)
ENCODER_2_SW: J5.11, R16.2, SW3.S1, U1.34 (IOT_44b)
GND: C1.2, C2.2, C3.2, C4.2, C5.2, C6.2, C7.2, C8.2, C9.2, C10.2, C11.2, C12.2, C13.2, C14.2, C15.2, C16.2, C17.2, C18.2, C19.2, C20.2, C21.2, C22.2, C23.2, C24.2, C25.2, C26.2, C27.2, C28.2, C29.2, C30.2, C31.2, C34.2, C35.2, C36.2, C37.2, C38.2, C39.2, C40.2, C41.2, C42.2, C43.2, C44.2, C45.2, C46.2, C47.2, C48.2, C49.1, C50.2, C51.2, C52.2, C53.2, C54.2, C55.2, C60.2, C61.2, D2.1 (K), D4.2 (A), D5.2 (A), D6.2 (GND), D7.2 (GND), D8.2 (GND), D12.2 (GND), IC1.5 (DGND), IC1.10 (AGND), IC1.20 (CE), IC1.21 (EP), IC2.4 (VSS), J1.5 (GND), J1.SH (Shield), J2.S, J2.TN, J3.S, J3.TN, J10.3, J10.4, J10.5, J10.6, J10.7, J10.8, JP1.2 (B), R10.2, R12.1, R14.1, R23.2, R25.1, R26.1, SW1.2, SW2.C, SW2.S2, SW3.C, SW3.S2, SW4.3 (C), SW5.3 (C), SW6.3 (C), U1.49 (GND), U2.6 (DGND), U2.20 (UGND), U2.24 (UGND), U2.27 (AGND), U2.28 (DGND), U2.33 (EP), U3.5 (+), U3.6 (-), U4.1 (GND), U5.4 (~EN), U5.5 (GND), U5.6 (GND), U5.7 (GND), U5.8 (GND), U6.4 (~EN), U6.5 (GND), U6.6 (GND), U6.7 (GND), U6.8 (GND), U7.1 (A0), U7.2 (A1), U7.3 (A2), U7.4 (GND), U7.7 (WP), Y1.2 (G), Y1.4 (G)
ICE_I2C_CLK: IC1.1 (CCLK), J5.2, TP10.1 (1_1), U1.23 (IOT_37a), U7.6 (SCL)
ICE_I2C_SDA: IC1.19 (CDATA), J5.4, TP9.1 (1_1), U1.25 (IOT_36b), U7.5 (SDA)
ICE_I2S_BCLK: IC1.6 (SCLK/DMIC_SCL), J4.6, U1.47 (IOB_2a)
ICE_I2S_DIN: IC1.9 (DSDIN), J4.8, U1.48 (IOB_4a)
ICE_I2S_DOUT: IC1.7 (ASDOUT), J4.1, U1.44 (IOB_3b_G6)
ICE_I2S_MCLK: IC1.2 (MCLK), J4.4, U1.46 (IOB_0a)
ICE_I2S_WS: IC1.8 (LRCK), J5.1, U1.38 (IOT_50b)
ICE_LED_0: R30.1, U1.39 (RGB0)
ICE_LED_1: R29.1, U1.40 (RGB1)
ICE_LED_2: R28.1, U1.41 (RGB2)
ICE_SPI0_MISO: IC2.2 (SO/SIO[1]), J6.7, U1.14 (IOB_32a_SPI_SO)
ICE_SPI0_MOSI: IC2.5 (SI/SIO[0]), J6.3, U1.17 (IOB_33b_SPI_SI)
ICE_SPI0_SCK: IC2.6 (SCLK), J6.5, U1.15 (IOB_34a_SPI_SCK)
ICE_SPI1_MISO: J4.7, U1.2 (IOB_6a), U2.9 (MISO)
ICE_SPI1_MOSI: J4.5, U1.4 (IOB_8a), U2.10 (MOSI)
ICE_SPI1_SCK: J4.3, U1.3 (IOB_9b), U2.8 (SCK)
IOB_13b: J6.2, U1.6 (IOB_13b)
IOB_16a: J6.4, U1.9 (IOB_16a)
IOB_18a: J6.6, U1.10 (IOB_18a)
IOB_20a: J6.8, U1.11 (IOB_20a)
IOB_22a: J6.10, U1.12 (IOB_22a)
IOB_23b: J6.9, U1.21 (IOB_23b)
IOB_24a: J6.12, U1.13 (IOB_24a)
IOB_25b_G3: J6.11, U1.20 (IOB_25b_G3)
IOB_29b: J6.13, U1.19 (IOB_29b)
IOB_31b: J6.14, U1.18 (IOB_31b)
IOT_51a: J5.9, U1.42 (IOT_51a)
NEOPIXEL_DIN: D6.4 (DIN), J5.7, U1.43 (IOT_49a)
unnamed: C1.1, C2.1, R1.1, R2.2
unnamed: C32.1, R11.2, R12.2
unnamed: C33.1, J3.T
unnamed: D2.2 (A), JP2.2 (B), R8.2
unnamed: D4.1 (K), L3.1, U5.2 (OUT)
unnamed: D5.1 (K), L4.1, U6.2 (OUT)
unnamed: D6.1 (DOUT), D7.4 (DIN)
unnamed: D7.1 (DOUT), D8.4 (DIN)
unnamed: D9.1 (K), R28.2
unnamed: D10.1 (K), R29.2
unnamed: D11.1 (K), R30.2
unnamed: D8.1 (DOUT), D12.4 (DIN)
unnamed: C28.1, IC1.15 (ADCVREF)
unnamed: C27.1, IC1.14 (DACVREF)
unnamed: C32.2, IC1.18 (MIC1P/DMIC_SDA), R13.1, TP7.1 (1_1)
unnamed: C33.2, IC1.12 (OUTP)
unnamed: C36.1, J1.4 (ID), R23.1
unnamed: J1.1 (VBUS), L1.2
unnamed: R14.2, R21.1, U2.4 (DCNF0), U2.5 (DCNF1)
unnamed: R10.1, U2.21 (RREF)
unnamed: R22.1, U2.3 (~RESET)
unnamed: J2.T, U3.3 (+)
unnamed: R11.1, U3.1, U3.2 (-)
unnamed: R24.1, R25.2, U5.3 (FB)
unnamed: R26.2, R27.1, U6.3 (FB)
PSRAM_SPI0_CS: IC2.1 (~CE), J6.1, U1.16 (IOB_35b_SPI_SS)
SW_1: J5.3, SW4.2 (B), U1.37 (IOT_45a_G1)
SW_2: J5.5, SW5.2 (B), U1.35 (IOT_46b_G0)
SW_3: J5.13, SW6.2 (B), U1.36 (IOT_48b)
USB_SPI1_CS: J4.2, U1.45 (IOB_5b), U2.32 (~SS)
USB_XSCI: C16.1, R9.2, U2.18 (XSCI), Y1.3
USB_XSCO: C17.1, R9.1, U2.19 (XSCO), Y1.1
VBUS: C18.1, C19.1, D3.2 (A), L1.1, TP5.1 (1_1), U2.30 (VBUS_DET)
VCC: C3.1, C4.1, C5.1, R3.2, U1.5 (VCC), U1.30 (VCC)
VCCPLL: R1.2, U1.29 (VCCPLL)
VDD: C39.1, C40.1, C43.1, C44.1, C46.1, C47.1, C51.1, C52.1, C53.1, D3.1 (K), D17.1 (K), TP4.1 (1_1), U4.3 (VI), U5.1 (VIN), U6.1 (VIN)
VPP_2V5: D1.1 (K), U1.24 (VPP_2V5)

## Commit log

2026-06-08 start schematic
    [audio_codec.kicad_sch, digi.kicad_pcb, digi.kicad_sch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]
2026-08-13 renders, etc
    [audio_codec.kicad_sch, bom.csv, bom.ods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]
